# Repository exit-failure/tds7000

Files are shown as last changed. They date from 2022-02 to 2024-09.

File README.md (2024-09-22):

# Tektronix TDS7000/CSA7000

## Various guides and files for maintaining and repairing the Tektronix TDS7000/CSA7000 oscilloscope series

There's still a lot to do and I will be adding bits and pieces from time to time when I find a minute or two. 

## You are very welcome to contribute by either creating pull or feature requests or, starting discussions or simpy sending me messages.  

## Replacing the Backup Battery and restoring NVRAM Settings

If your scope is stuck on the splash screen of the TekScope application (see screenshot below), the most likely reason is that the memory contents of the NVRAM have been erased. Usually this is the case when the backup battery of said NVRAM located on the  the PowerPC Board (the lower of the two motherboards) has been depleted. This means that you have to replace the battery and restore the NVRAM setting. 

I've compiled a tutorial on how to do that here: [Replacing the Backup Battery and restoring NVRAM Settings](NVRAM/README.md)

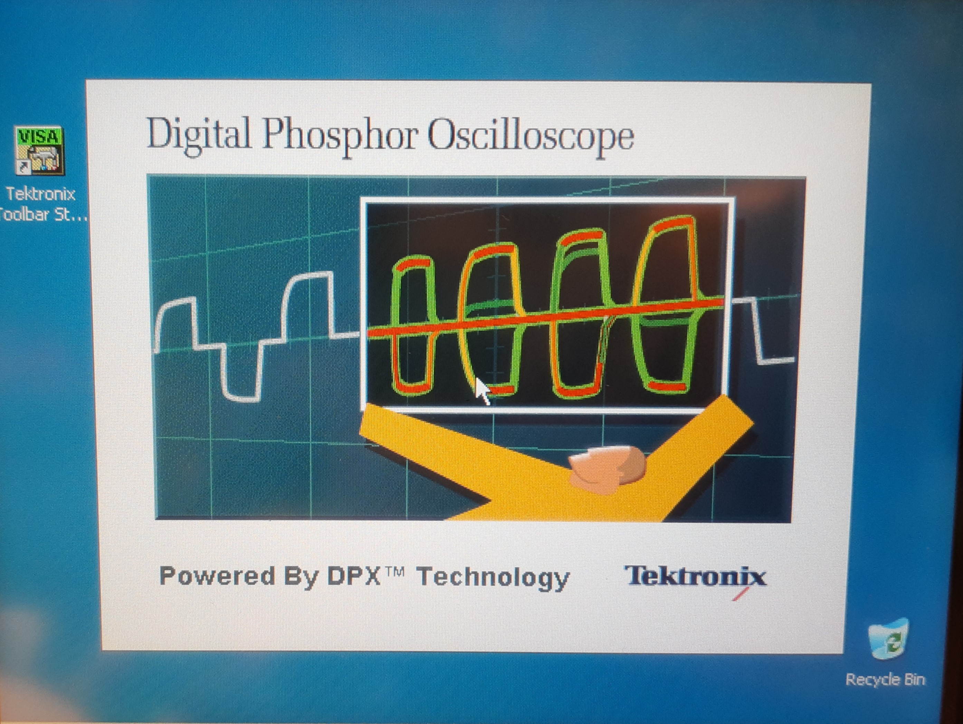
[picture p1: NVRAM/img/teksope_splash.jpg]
<br>
the TekScope application splash screen

I also created a bracket for installing 2.5" SSDs and HDDs: [3D printable SSD/HDD holder](3D%20printable%20SSD%20holder)

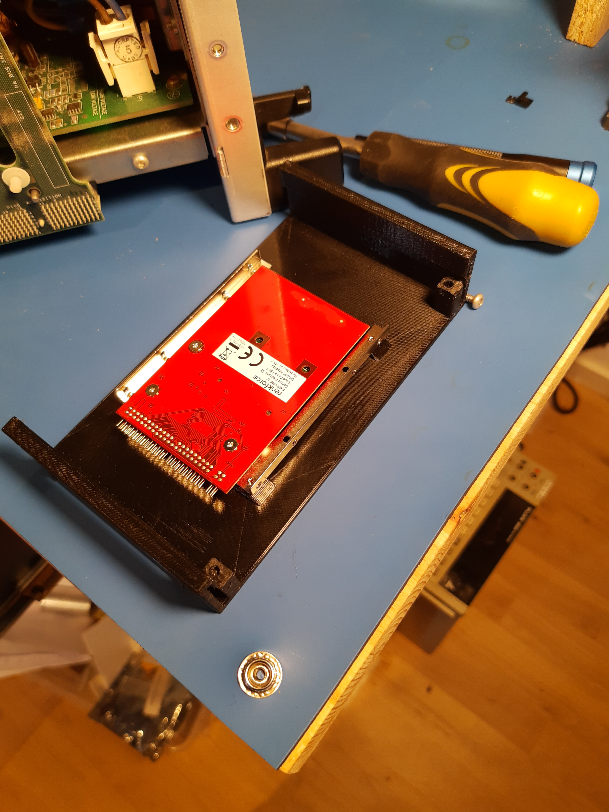
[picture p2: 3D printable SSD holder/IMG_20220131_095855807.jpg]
<br>

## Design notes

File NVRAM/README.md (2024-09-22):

# Replacing the Backup Battery and restoring NVRAM Settings when the Battery has run empty

If your scope is stuck on the splash screen of the TekScope application (see screenshot below), the most likely reason is that the memory contents of the NVRAM have been erased. Usually this is the case when the backup battery of said NVRAM located on the  the PowerPC Board (the lower of the two motherboards) has been depleted. This means that you have to replace the battery and restore the NVRAM settings.

<br>
the TekScope application splash screen

# Replacing the Battery

Since the Power modules from Dallas aren't available any more I modified the existing one for easier battery replacement in the future.

### 1. Removing the PowerCap module from the NVRAM

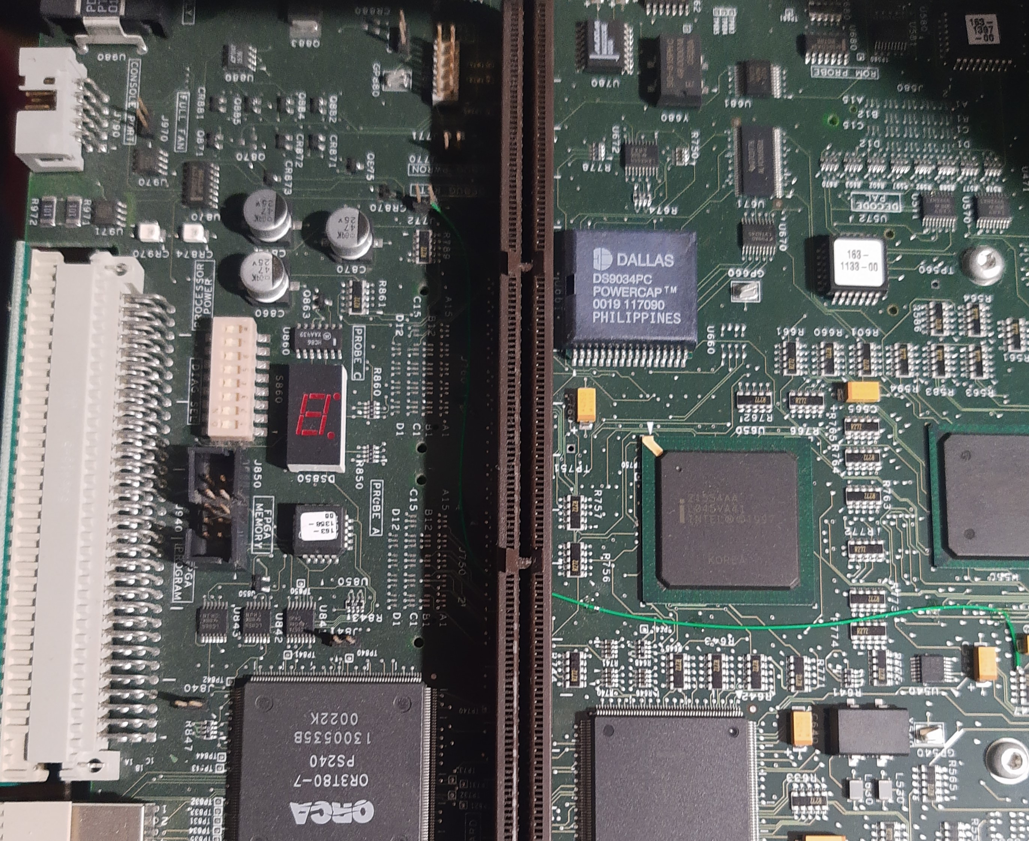
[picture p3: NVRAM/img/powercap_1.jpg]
   

   Push a small screwdriver into the slit on the side of the PowerCap module and lever it off. You do __not__ need a lot of force for that.  

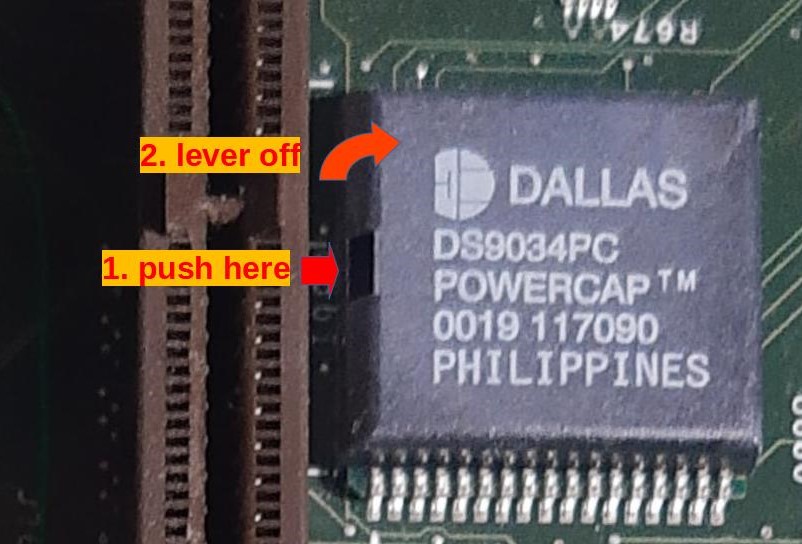
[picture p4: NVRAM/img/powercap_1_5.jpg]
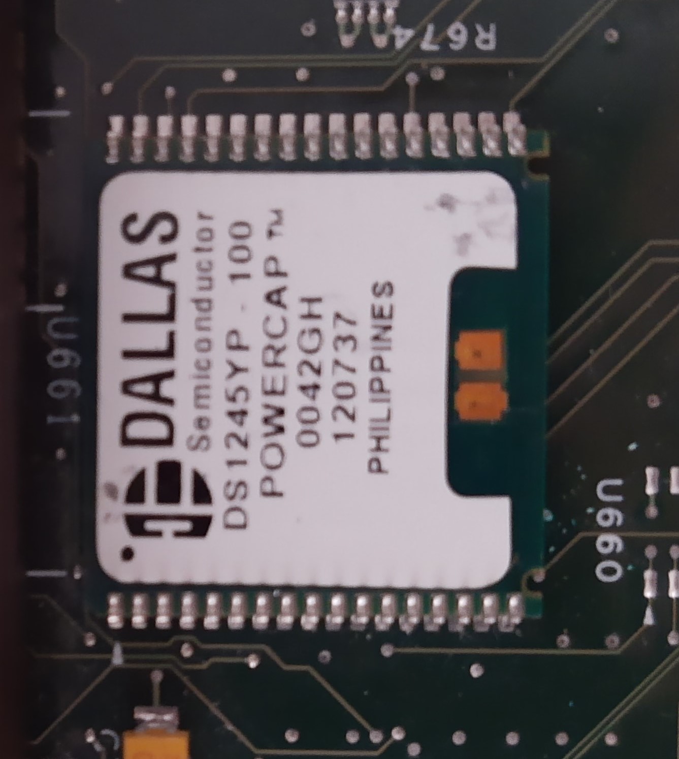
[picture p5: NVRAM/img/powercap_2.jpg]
    

### 2. Removing the old battery

   The tabs are spot welded to the button cell. In my case they felt like they were very firmly attached to the battery I just drilled out the spot welds with a 1mm tungsten carbide drill bit and a Dremel. After that I was able to take out the battery.

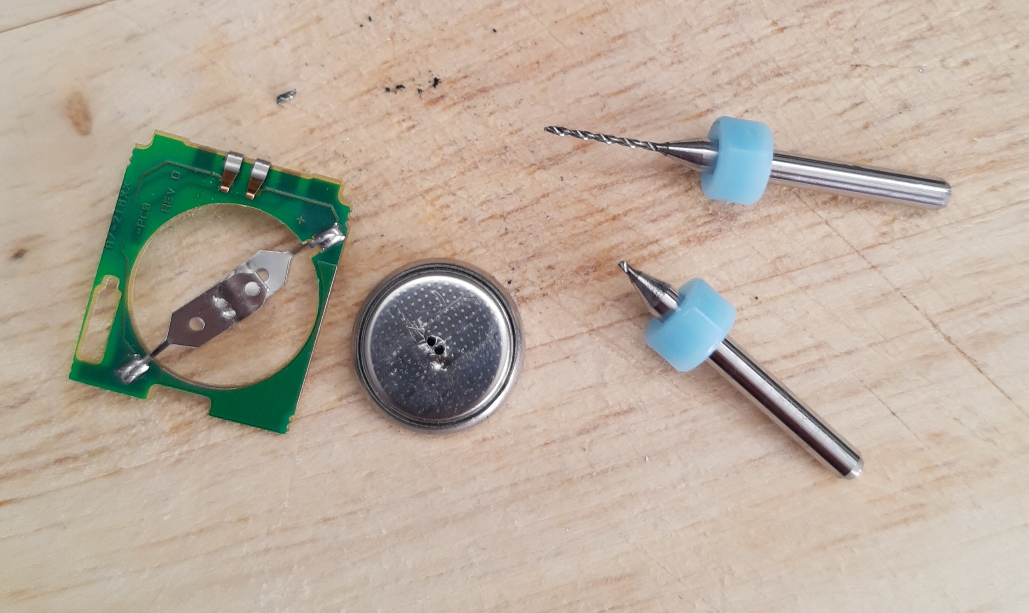
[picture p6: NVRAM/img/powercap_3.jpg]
   

### 3. Attaching a battery holder to the PowerCap module

   I glued a CR2032 holder to the top of the module and soldered wires between the battery holder and the PCB on the underside. I had to cut small slits into the sides of the plastic housing to be able to route the wires properly. Otherwise the module won't clip back onto the NVRAM. I also used some tape to insulate the old battery tabs in order to avoid short circuits.

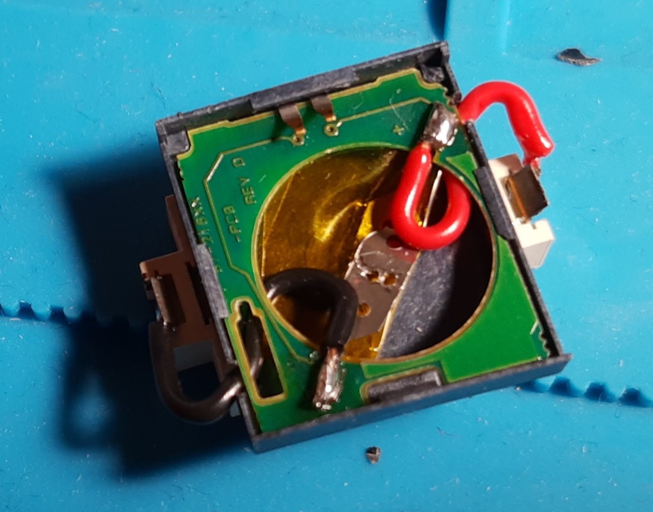
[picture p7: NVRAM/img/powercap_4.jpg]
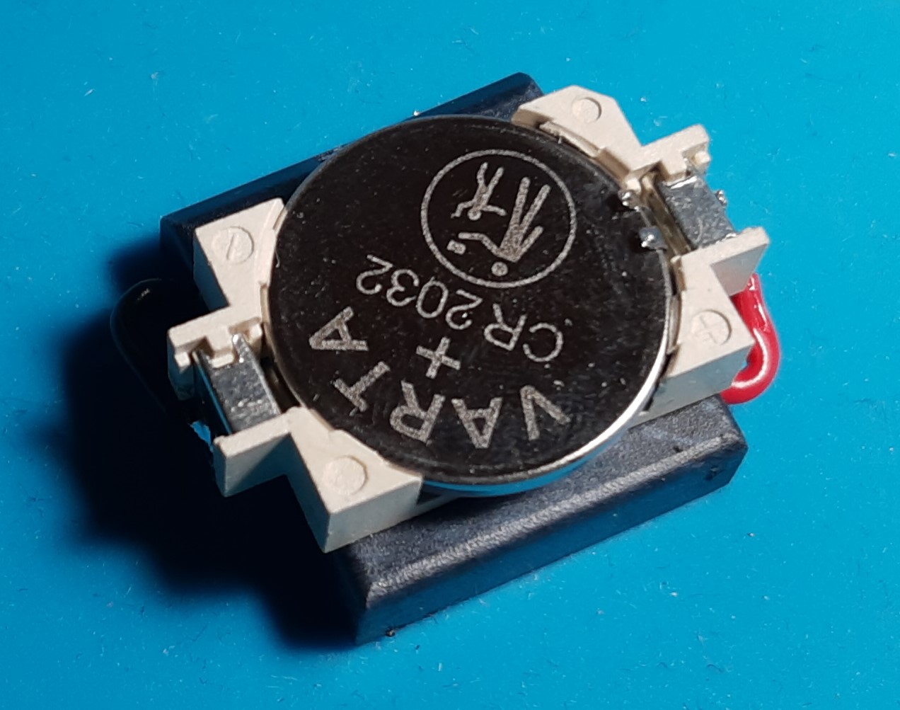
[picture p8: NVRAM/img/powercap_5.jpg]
    

### 4. Putting the Power module back on top of the NVRAM

   Just hook the module onto the NVRAM chip on the opposite side of the slit and push it down until it latches. Be careful to not bend the contacts in the wrong direction.  

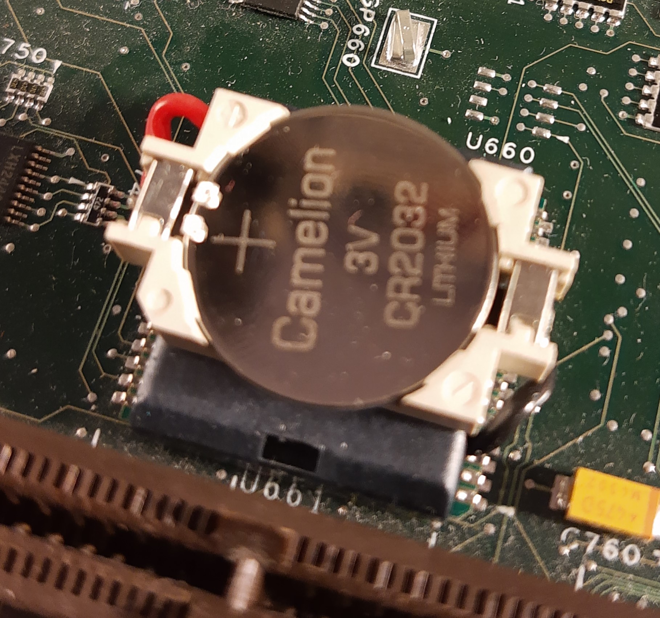
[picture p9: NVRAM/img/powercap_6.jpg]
   

# Restoring the NVRAM Settings

### 1. Get yourself a PC with a serial interface ot a USB to serial interface

### 2. Connect the scope to the serial interface

You can use a standard 10-pin IDC to DB9 adapter. __Notice that there are two types that are wired up differently.__ The one that is required here is the older style (DTK/INTEL style). The new style (AT/EVEREX style) is not suitable for our task.  If you are using such an adapter, please make sure that the pinout matches the one in the table below.  If you do not have an adapter at hand connect, just use a couple of jumper wires. This works just as well. The absolute minimum of lines you'd have to connect are __`RX`__, __`TX`__ and __`GND`__.

#### The Pinout of the IDC connector is as follows

male IDC connector on a TDS7104:  
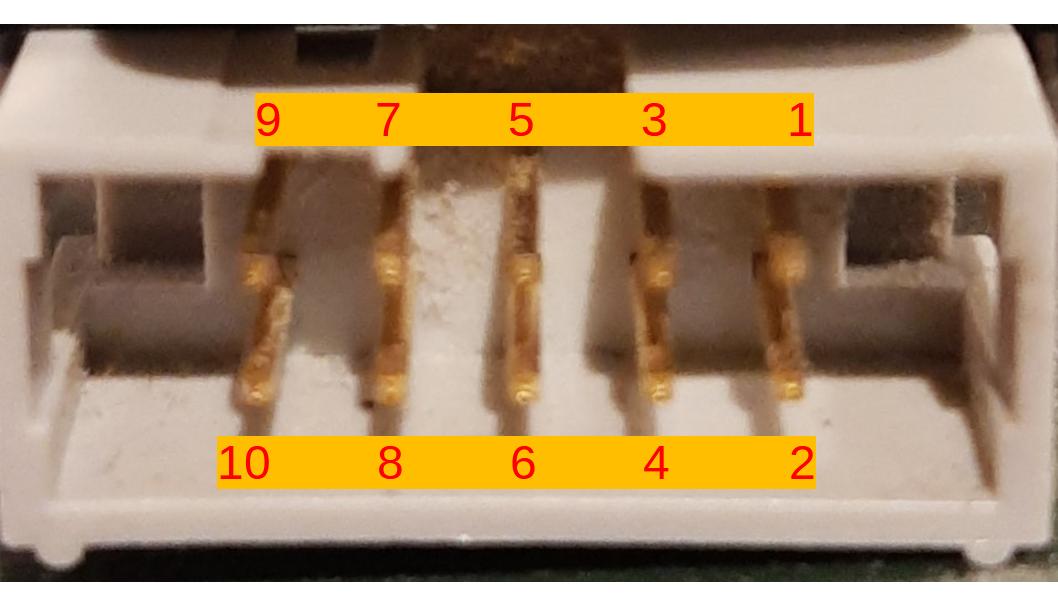
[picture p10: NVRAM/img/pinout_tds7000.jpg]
<br>

female IDC connector on a IDC-serial adapter:  
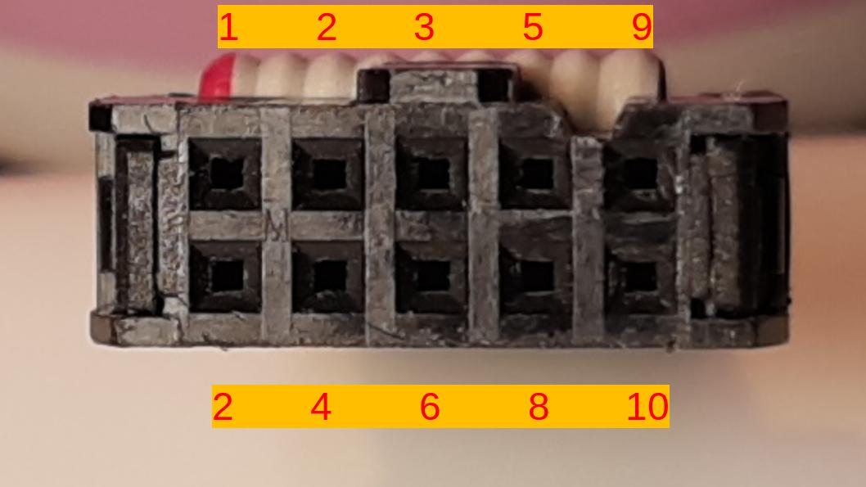
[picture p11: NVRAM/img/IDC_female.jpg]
<br>

| 10 pin IDC (TDS7000/adapter) | signal | description |
|--|--|--|
|1|DCD|Data Carrier Detect|
|2|DSR|Data Set Ready|
|3|RX|Receive Data|
|4|RTS|Request to Send|
|5|TX|Transmit Data|
|6|CTS|Clear to Send|
|7|DTR|Data Terminal Ready|
|8|RI|Ring Indicator|
|9|GND|System Ground|
|10|not connected|---|

#### The pinout of a standard maserial port (the type you find on a PC) is as follows

*Please be make sure that you have the pinout for the correct gender. The female socket has an inverted pinout.*

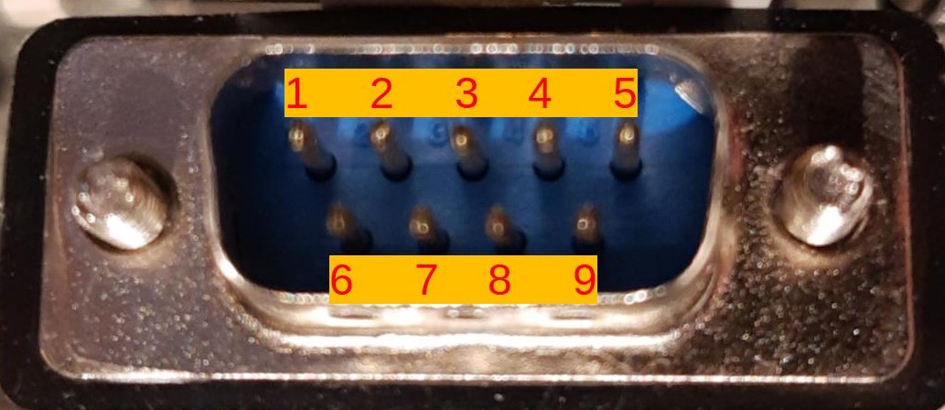
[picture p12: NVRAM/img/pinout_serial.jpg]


| PIN DB9 male (serial)| signal |
| -- | -- |
|1|DCD|
|2|RX|
|3|TX|
|4|DTR|
|5|GND|
|6|DSR|
|7|RTS|
|8|CTS|
|9|RI|

### 3. Connect to the serial interface with a terminal software of your liking.  

* I used [Tera Term](https://teratermproject.github.io/index-en.html). Tera Term should come with the correct serial port settings out of the box. If you want to check, you can find the settings under `Setup` -> `Serial Port...`.  
* For Linux I often use [CuteCom](http://cutecom.sourceforge.net/) if I want something with a graphical user interface.
*  I usually use [HTerm](https://www.der-hammer.info/) but for some reason the communication didn't work properly after sending a random character to interrupt the boot process.  

The required settings for the serial interface are:

|setting|value|
|--|--|
|baud rate|9600|
|data bits|8|
|stop bits|1|
|parity|none|
|flow control|no|

#### Please note that you need to reinstall the upper main board again. Otherwise the scope will not turn on.

1. Start your terminal software and connect to the serial port. After that start your scope.
2. When the countdown appears send any character to interrupt the startup process.
3. Send `?` to display the main menu.

### 4. Set the settings to their proper values:

In the main menu send `c` to get into the configuration dialog.
The following table shows the right settings for a TDS7104 other models may require other settings but I would expect them to be the same.

| setting name | value |
| -- | -- |
| boot device |sm|
| processor number |0|
| host name |host|
| file name |c:/vxBoot/vxWorks.st|
| inet on ethernet (e) |192.168.0.2:ffffff00|
| inet on backplane (b) |192.168.0.0:ffffff00|
| host inet (h) |192.168.0.1|
| gateway inet (g) |192.168.0.2|
| user (u) | anonymous |
| ftp password (pw) |anonymous|
| flags (f) |0x1000|
| target name (tn) |tds7000|
| startup script (s) |c:/vxBoot/topScript.hw|
| other (o) |nvfs=0x1000|

Go through the list and enter the right values. Send `.` to clear options that have wrong values set and enter the options menu again after you are through to set the option. Go through the menu one last time to make sure everything is set correctly.

When you're done send an `@` to continue booting the scope when the scope software splash screen is already showing. Otherwise switch the scope off, make sure that Windows boots correctly and turn it back on again. The scope software should now start without a problem.

## Troubleshooting

* If you have trouble using the menu properly because the menu always seems to skip every other option, try changing the line break characters, your terminal software sends after pressing enter. If it is set to send __`\r`__ (carriage return) __AND__ __`\n`__ (line feed) try instead using ___only one or the other___.

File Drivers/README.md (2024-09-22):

# You can find various drivers for the scope's application PC here.

They should work with Windows 98 and XP

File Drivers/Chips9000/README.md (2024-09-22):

# This is the driver for the application PC's graphics card

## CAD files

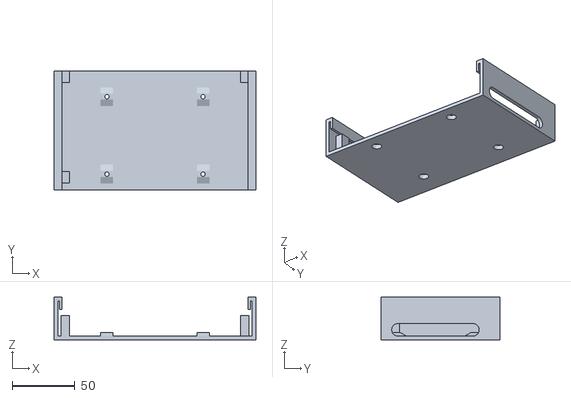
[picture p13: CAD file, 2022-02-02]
3D printable SSD holder/holder.stl
161.0 x 94.5 x 34.0

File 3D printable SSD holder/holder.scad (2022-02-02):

$fn = 200;

length = 155;
width = 84.5+10;
materialThickness = 3;

standoffHeight = 3;
ssdHeight = 14 + standoffHeight;

screwHoleDia = 3.5;
screwXDistance = 76.6;
screwYDistance = 61.71;
screwZDistance = 3;

x1 = (length-screwXDistance)/2;
x2 = x1+screwXDistance;
y1 = 5+7.5;
y2 = y1+screwYDistance;

slitWidth = 60;
slitOffset = ((screwYDistance-slitWidth)/2)+y1;

module bracket() {
	thickness = 3.5;
	slitWidth = 1.5;
	slitHeigtht = 7;
	bracketHeight = 10;
	plateThickness = 4;
	
	union() {
		translate([0,0,ssdHeight+materialThickness+plateThickness])
			difference() {
				cube([thickness, width, bracketHeight]);			
				cube([slitWidth, width, slitHeigtht]);
			}
			
		translate([-materialThickness, 0, 0]) 
			cube([materialThickness, width, ssdHeight+bracketHeight+materialThickness+plateThickness]);
	}
}

/*
module side() {
	difference() {	
		translate([0, -materialThickness, 0]) 
			cube([length, materialThickness, 7 + materialThickness]);
		
		translate([(155-screwXDistance)/2, 0, screwZDistance+materialThickness])
			rotate(a=[90,0,0])
				cylinder(d=screwHoleDia, h=2*materialThickness, center = true);
		
		translate([((155-screwXDistance)/2)+screwXDistance, 0, screwZDistance+materialThickness])
			rotate(a=[90,0,0])
				cylinder(d=screwHoleDia, h=2*materialThickness, center = true);
	}
}
*/

module holder() {	
	holderWidth = 6.5;
	holderLength = 9;
	holderHeight = ssdHeight-0.8;
	
	holeDia = 4;
	holeDepth = 5;
	holeYDist = 7.7-(holeDia/2);
	
	difference() {	
		translate([0, width-(holderLength/2), (holderHeight/2)+materialThickness])
			cube([holderWidth, holderLength, holderHeight], center = true);
		
		translate([0, width-holeYDist, holderHeight+materialThickness-(holeDepth/2)])
			cylinder(d=holeDia, h = holeDepth, center = true);
	}
}

module stabilizer() {
	holderWidth = 6.5;
	holderLength = 9;
	holderHeight = ssdHeight-0.8;
	
	translate([0, 10, (holderHeight/2)+materialThickness])
		cube([holderWidth, holderLength, holderHeight], center = true);
}

module base() {
	difference() {
		union() {
			cube([length, width, materialThickness]);
			translate([x1, y1, 0])  standoff();
			translate([x2, y1, 0])  standoff();
			translate([x1, y2, 0])  standoff();
			translate([x2, y2, 0])  standoff();
		}
		
		translate([x1, y1, -materialThickness])
			cylinder(d=screwHoleDia, h=10*materialThickness);
		
		translate([x2, y1, -materialThickness])
			cylinder(d=screwHoleDia, h=10*materialThickness);
		
		translate([x1, y2, -materialThickness])
			cylinder(d=screwHoleDia, h=10*materialThickness);
		
		translate([x2, y2, -materialThickness])
			cylinder(d=screwHoleDia, h=10*materialThickness);
		
		translate([x1, y1, 0]) screwCutout();
		translate([x1, y2, 0]) screwCutout();
		translate([x2, y1, 0]) screwCutout();
		translate([x2, y2, 0]) screwCutout();
	}
}

module standoff() {
	standoffWidth = 10;
	standoffLength = 15;
	
	difference() {
		translate([0, 0, (standoffHeight/2)+materialThickness])
			cube([standoffWidth, standoffLength, standoffHeight], center = true);
		
		translate([0, -10, (standoffHeight/2)+materialThickness])
			rotate(a=[30, 0, 0])
				cube([15,20,5], center = true);
		
			rotate([0,0,180]) 
				translate([0, -10, (standoffHeight/2)+materialThickness])
					rotate(a=[30, 0, 0])
						cube([15,20,5], center = true);
	}
}

module screwCutout() {
	cutoutDia = 8;
	cutoutHeight = materialThickness+1;
	
	translate([0, 0, cutoutHeight/2])
		cylinder(d=cutoutDia, h=cutoutHeight, center = true);
}

union() {
	base();
	
	translate([4+2,0,0])
		holder();
	
	translate([length-(4+2),0,0])
		holder();
	
	bracket();
	
	translate([4+2,0,0])
		stabilizer();
	
	difference() {
		translate([length,width,0])
			rotate(a=[0,0,180])
				bracket();
		
		translate([length-materialThickness, slitOffset, materialThickness])
			cube([10,slitWidth,10]);
		
		translate([length-materialThickness, slitOffset, materialThickness+5])
			rotate(a=[0, 90, 0])
				cylinder(d=10, h=10);
		
		translate([length-materialThickness, slitOffset-2+screwYDistance, materialThickness+5])
			rotate(a=[0, 90, 0])
				cylinder(d=10, h=10);
	}
}

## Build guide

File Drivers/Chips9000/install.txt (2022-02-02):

     Windows 2000 -- Asiliant Driver Installation Procedure
                     for Chips And Technologies hardware.
   --------------------------------------------------------------------------  

        Click the "Start" button, then select the "Settings" tab and click on
        "Control Panel".
	
        Click on the "Display" icon to start the Display Properties window.
	
	Click on the "Settings" tab, and then click on "Advanced..." button.

        Select the "Adapter" tab, then the "Properties" button found there.

        Select the "Driver" tab, then the "Update Driver..." button.

        Select the radio button that begins "Display a list of the known..."
        and press the "Next" button.

        Click the "Have Disk..." button and select the location of the
        driver files.

        Make a selection from the list provided, and click "Next".

        You may need to shutdown and reboot the system for the changes to
        take effect.

	When the system has restarted, the default graphics mode ( usually
	640x480x256color ) has been automatically selected. 

To change the display resolution and/or colors...
-------------------------------------------------
        Click the Start button, then go to Settings and click on Control Panel.
	
        Click on the Display icon to start the Display Properties window. 
	
	Click on the Settings tab.
	
	A new screen setting can be selected using either of the following
        methods:

          1:  Use the slide-bar in the Desktop Area to select new setting.
	    
	  2:  Click on List All Modes. From the list provided, select a new  
	      setting, then click OK or press enter.

        Click the Apply button to make changes.

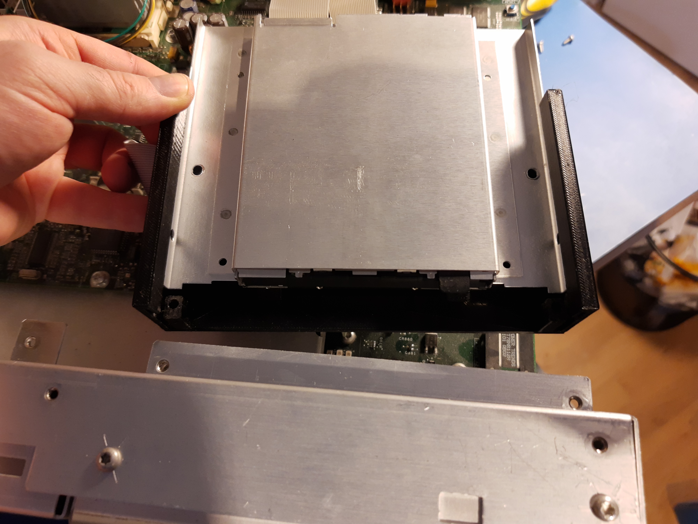
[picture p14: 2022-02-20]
3D printable SSD holder/IMG_20220131_100013934.jpg

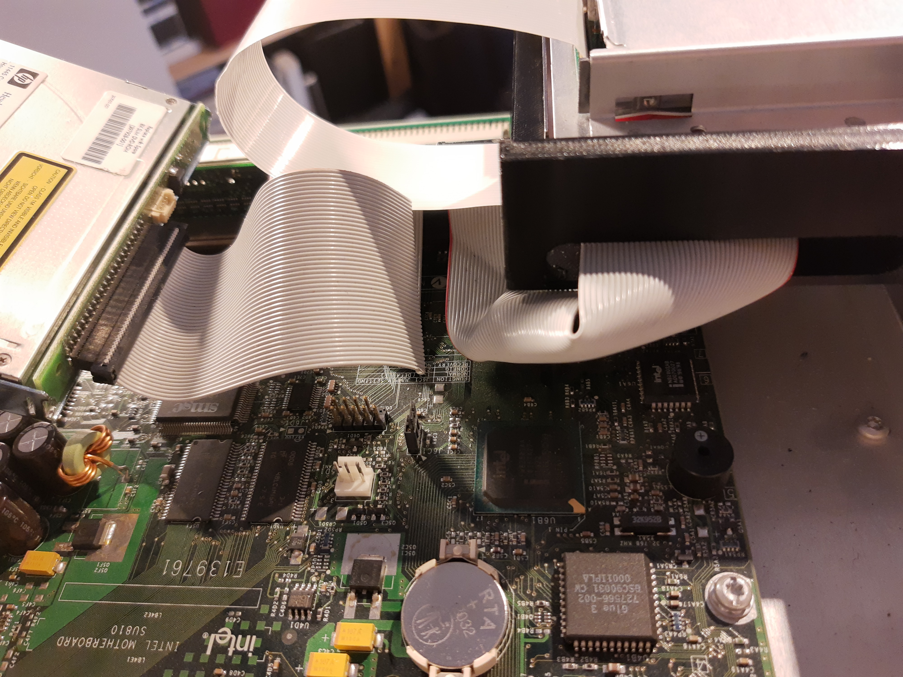
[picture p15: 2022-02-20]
3D printable SSD holder/IMG_20220131_100708800.jpg

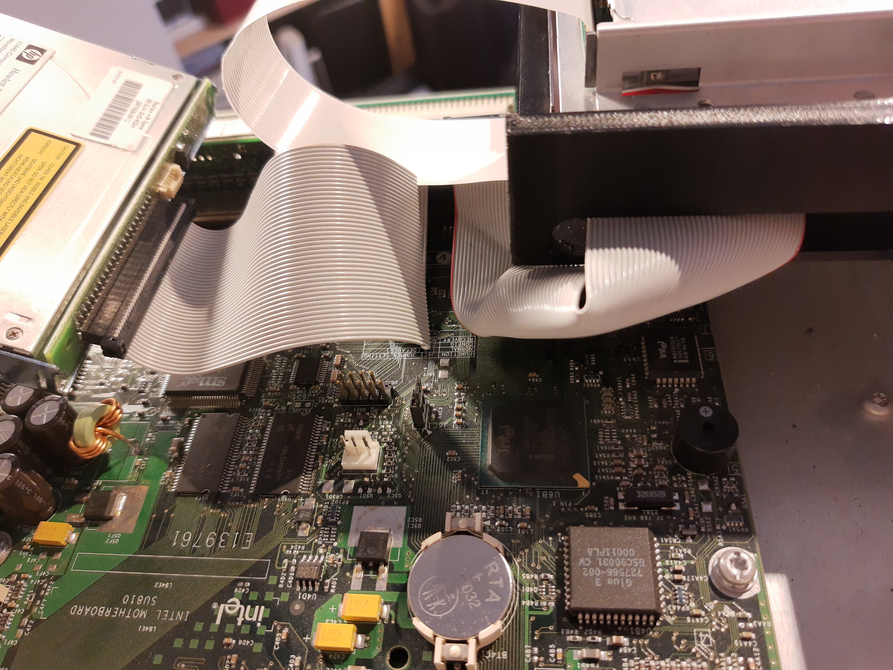
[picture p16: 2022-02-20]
3D printable SSD holder/IMG_20220131_100710896.jpg

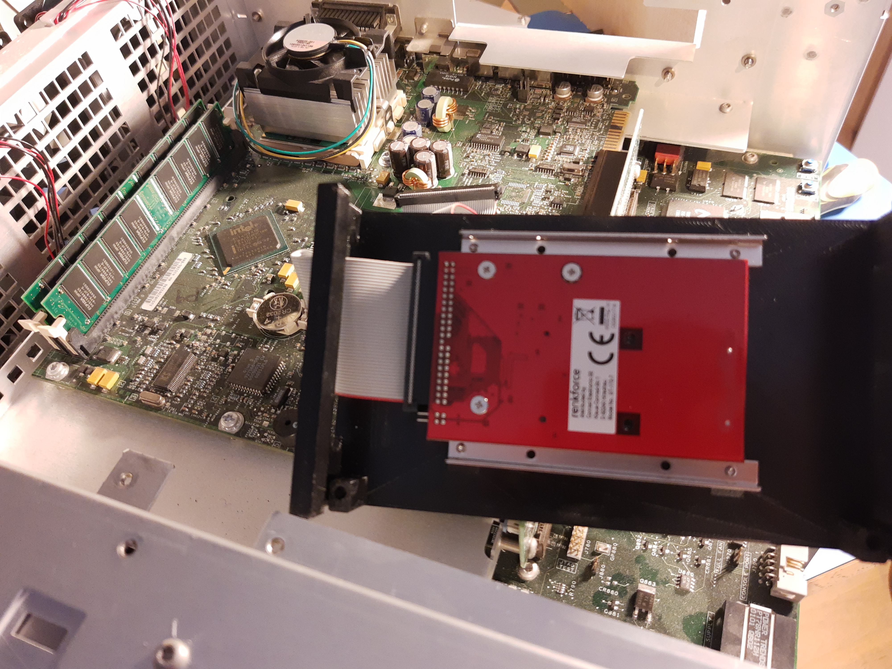
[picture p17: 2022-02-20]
3D printable SSD holder/IMG_20220131_095956155.jpg

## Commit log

2022-02-02 slimmed down options script executable
    [holder.scad, holder.stl]
2022-02-02 renamed 3D model
    [holder.scad, holder.stl]
2022-02-20 updated NVRAM reset procedure and added photos of battery replacement
2022-02-20 First complete version of battery replacement and NVRAM reset procedure
2022-02-20 added photos for the 3D printable SSD holder
2024-09-22 corrected connector gender for DB9 serial connector
